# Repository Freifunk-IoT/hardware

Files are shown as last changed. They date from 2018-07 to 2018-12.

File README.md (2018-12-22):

# Freifunk-IoT-Hardware

| Hardware/Details | Typ  | Messungen/Sensor | Stückpreis ca. | Status | Bemerkungen |
| --- | ---- | --- | --- | --- | --- |
| [ESP-03 mit BME280](https://github.com/Freifunk-IoT/hardware/blob/master/esp8266/enviroment/esp03_bme280/ESP03_BME280.md) | PCB  | BME280 (Temperatur, Luftfeuchtigkeit, Luftdruck) | ? | funktioniert (Rev. 2) | kann Deep Sleep, inkl. Sicherung |
| ESP-03 mit BME280/DHT22 (Hybrid) | PCB  | BME280 (Temperatur, Luftfeuchtigkeit, Luftdruck) oder DHT22 (Temperatur, Luftfeuchtigkeit) | ? | Idee | |
| ESP-01 mit DHT11 | Mod  | DHT22 (T) | ? | Idee | Modul gibt es fertig bei Aliexpress etc., vmtl. gut für den "schnellen Einstieg". |
| [ESP-01 mit DHT*/BME280 "Workshop Board"](https://github.com/Freifunk-IoT/hardware/blob/master/esp8266/enviroment/esp01_DHT22_USB/ESP01_DHT22.md) | PCB  | BME280 (Temperatur, Luftfeuchtigkeit, Luftdruck) oder DHT22 (Temperatur, Luftfeuchtigkeit) | ? | Hardware funktioniert und ist getestet, Software fehlt | Einsteigerplatine mit Linearregler (USB-Anschluss) + entsprechende Absicherung, wahlweise BME280 oder DHT*, kleinste Bauteile: 1206, alles andere THT |
| Outdoor-Full-Feature-Board | PCB  | BME280 | ? | Idee | inkl. BMS für LiIon, Spannungsreglern (Buck/Boost), Absicherungen, Deep Sleep, optimiert für lange Laufzeiten |
| Wemos D1 mini mit DHT* | PCB | DHT* (Temperatur + Feuchtigkeit) | ? | Idee | Für einfachen Einstieg (5V USB Eingang) |

Wenn du Freifunk-IoT auf anderer Hardware betreibst, neue Sensoren eingebunden hast, eine praktische Platine entworfen hast oder einfach nur dein Aufbau vorstellen willst, mach einfach einen eigenen Ordner für dein Projekt auf und stelle es vor!

*Bitte beachtet: Dieses Repository ist mehr für die technische Entwicklung und Vorstellung gedacht. Reine Tutorials sind auf der [website](https://github.com/Freifunk-IoT/website) besser aufgehoben.*

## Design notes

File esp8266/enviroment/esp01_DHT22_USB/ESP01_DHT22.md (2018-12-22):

# ESP-01 mit DHT22 und USB-Spannungsversorgung
(by [@morasp](https://github.com/morasp))
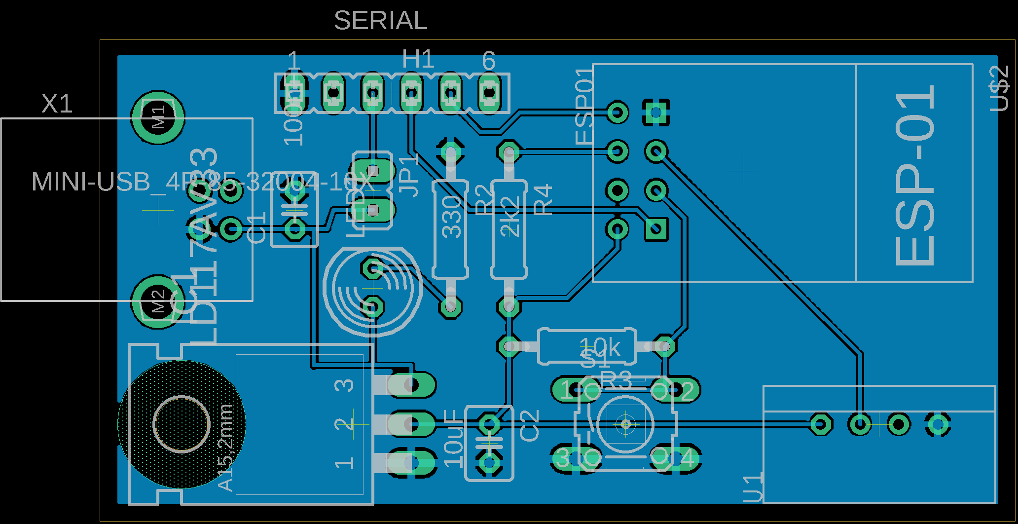
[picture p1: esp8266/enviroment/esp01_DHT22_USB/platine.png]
Vorläufige Platine


Diese Platine ist gedacht für Lötanfänger und Workshops. Deshalb sind alle Bauteile als THT ausgeführt. Außerdem erfolgt die Spannungsversorgung über USB.

### Features

- Temperatur- und Luftfeuchtigkeitsmessung mit DHT22
- direkter Anschluss eines Programmieradapters
- Spannungsversorgung über USB
- Keine SMD-Bauteile

### Bauteile
| Bezeichnung | Anzahl |
|---|---|
| Platine | 1|
| ESP-01 | 1|
| DHT22 | 1 |
| Widerstand 10k | 1 |
| Widerstand 2k2 | 1 |
| Widerstand 330 | 1 |
| Taster | 1 |
| USB-B Buchse  THT | 1 |
| Kondensator 100nF | 1 |
| Kondensator 10 uF | 1 |
| LF33ABV | 1 |
| Buchsenleiste 2,54 mm | 1 |
| Jumper | 1 |
| LED 5mm | 1 |

Genaue Teilebezeichungen, Preise und Links folgen.

### Changelog
Rev1:
Initial Layout

Rev2:
Fixed Programmer-Pinout to fit FTDI-Breakout

Rev3:
Changed voltage-regulator to fit pseudo-standart pinout

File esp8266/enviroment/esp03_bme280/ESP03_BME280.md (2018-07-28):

# ESP-03 mit BME280 

(by [@margau](https://github.com/margau))

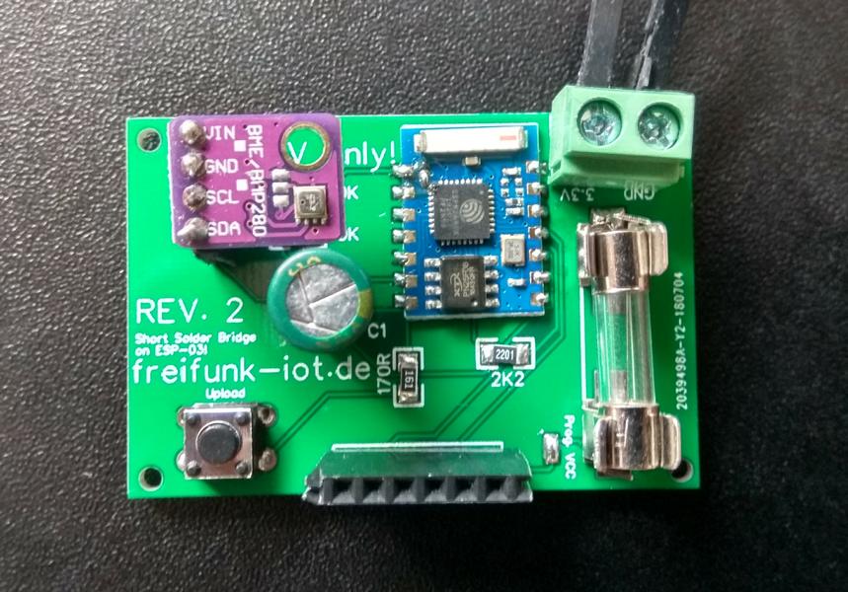
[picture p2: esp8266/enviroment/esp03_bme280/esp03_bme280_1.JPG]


Diese Platine bietet, unter Verwendung von SMD-Bauelementen, einen schnellen Aufbau eines Temperatursensors an. Nötig ist zum Betrieb nur eine externe 3,3V-Spannungsversorgung. Auf LED's etc. wurde verzichtet, um einen möglichst lange andauernden Akkubetrieb möglich zu machen. Der Aufbau dauert für geübte ca. 10-15 Minuten.

### Features

- Temperatur-, Luftfeuchtigkeits und Luftdruckmessung mit BME280
- Sicherung
- direkter Anschluss eines Programmieradapters

### Bauteile

| Bezeichnung | Quelle | Anzahl | Preis (07/2018) |
| --- | --- | --- | --- |
| Platinen | JLCPCB | 1 (10er Set) | 10 Stück: ~10 €  inkl. Versand |
| ESP-03 | China (Ebay, Ali...) | 1 | ~ 2,20 € |
| BME280 4-pin-Breakout | Amazon, Ebay, Aliexpress | 1 | ~ 2,20€ - 10 €/Stück |
| Elektrolytkondensator (z.B. 330 µF 16V) | Jeder Elektronikhändler, Empf.: Sets | 1 | < 0,10 € |
| SMD-Widerstand 1206 10kΩ | Jeder Elektronikhändler, Empf.: Sets | 2 | ~ 1ct/Stück |
| SMD-Widerstand 1206 2,2kΩ | Jeder Elektronikhändler, Empf.: Sets | 1 | ~ 1ct/Stück |
| SMD-Widerstand 1206  170Ω | Jeder Elektronikhändler, Empf.: Sets | 1 | ~ 1ct/Stück |
| Feinsicherung 1A 6*20mm | Jeder Elektronikhändler, Empf.: Sets | 1 | |
| Sicherungshalter | Conrad:  533920 - 62, Ali, einige Elektronikhändler | 2 | ~ 14ct/Stück Conrad, ~1,20 € für 100 Stück (Aliexpress) |
| Buchsenleiste 2,54 mm | Diverse Elektronikhändler, am besten als Set | 1 * 4 pin, 1 * 6 pin | Aliexpress: 1,66 € für 10 * 40 pins |
| 5,08 mm Schraubklemme | Ebay, Aliexpress ... | 1 | ~ 1,20 € für 20 Stück |
| Miniaturtaster | Ebay, Aliexpress; sinnvoll im Set | 1 | < 10 ct |
| FTDI232(o.ä.) USB-Seriell Programmieradapter, **3.3V!**, auf Pinbelegung achten! | Ebay, Aliexpress, ... | 1 | ~1,50 € |

Weiterhin wird für den Betrieb eine 3.3V-Spannungsversorgung benötigt, auch hier gibt es fertige Module. **Ein Betrieb mit 5V zerstört die Schaltung!**

### PCB
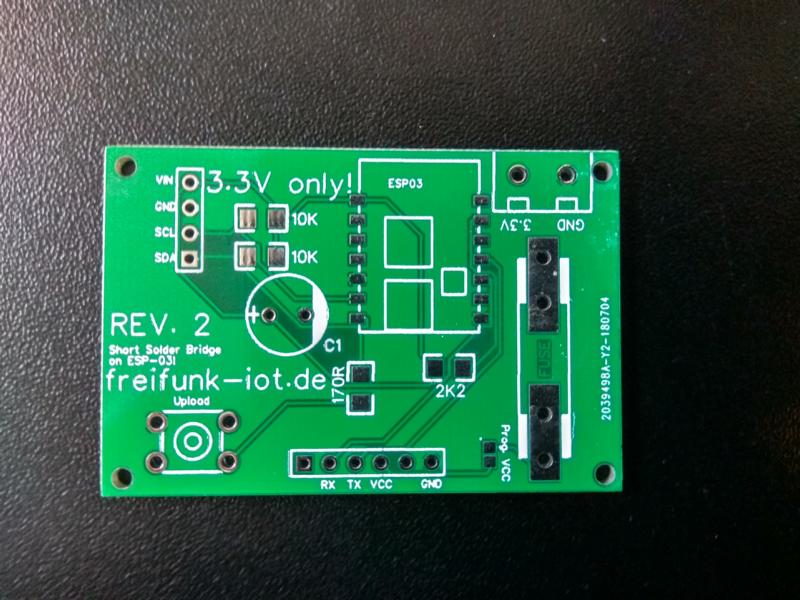
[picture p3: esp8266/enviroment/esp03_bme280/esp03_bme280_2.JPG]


Die Produktionsdaten im Gerber-Format befinden sich im Ordner "Gerber". Das Design ist im Onlineeditor von EasyEDA entstanden, und kann dort auch weiterbearbeitet werden: [Zum Projekt bei EasyEDA](https://easyeda.com/margau/FreifunkIoT-BME280-ESP03)

Die im Bild dargestellte Platine wurde bei JLCPCB bestellt, bei Kosten von ca. 9$ für 10 Stück inkl. Versand und einer Lieferzeit von ca. 10-20 Tagen.

### Aufbau
Es empfiehlt sich beim Aufbau zunächst mit den SMD-Komponenten zu beginnen, und sich dann zu den größeren Bauteilen vorzuarbeiten.
Wenn beim Programmiervorgang eine Stromversorgung über den Programmieradapter gewünscht ist, muss die Lötbrücke Prog. VCC geschlossen werden.

Bei Verwendung des Deep Sleep muss weiterhin eine Lötbrücke auf der Platine des ESP-03 geschlossen werden, dies erfordert etwas Geschick und Vorsicht.

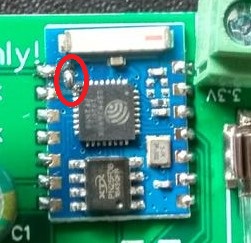
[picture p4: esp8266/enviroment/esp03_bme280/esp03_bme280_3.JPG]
Lötbrücke


Man kann das BME280-Breakout-Board direkt verlöten, oder (besonders im Falle eines defektes) austauschbar über eine Buchsenleiste montieren. Hierbei einfach darauf achten, dass die Beschriftung am BME280-Breakout-Board mit der auf der Platine übereinstimmt.

Die externe Stromversorgung des Boards **muss** mit 3.3V erfolgen, andernfalls werden Bauteile beschädigt.

### Programmierung
Die Programmierung erfolgt mit einem USB-Seriell-Adapter aus der Arduino-IDE. 
Hierzu ist folgender Sketch geeignet: (https://github.com/Freifunk-IoT/esp8266-examples/blob/master/bme280/esp01/esp01-bme280-sketch/esp01-bme280-sketch.ino)

Folgende Änderungen müssen noch vorgenommen werden:
- Die richtige Sensor-ID muss eingetragen werden
- ggf. den Kommentar in Zeile 143 entfernen und Zeile 145 auskommentieren, um den Deep Sleep zu nutzen

In der Arduino-IDE muss die ESP8266-Umgebung installiert sein, der richtige COM-Port ausgewählt werden und das Board "Generic ESP 8266 Module" ausgewählt sein. 

Nach korrekter Verbindung (Pin's prüfen!) und Einstellung der Spannung von **3.3 V** am USB-Seriell Adapter kann man den Upload-Knopf am Board gedrückt halten, die Verbindung herstellen und in der IDE den Upload anstoßen. 

Sieht man an den LEDs des Adapters einzelnes Aufblitzen, kann der Upload-Taster losgelassen werden; der Upload sollte nun erfolgen. Falls nicht, sind noch einmal alle Verbindungen etc. zu prüfen.

*Die Beschriftung am Programmieranschluss ist 1:1, d.h., RX wird mit RX am Adapter und TX mit TX am Adapter verbunden. Die Belegung ist die der üblichen FTDI232-Adapter - falls eine andere Reihenfolge der Pins vorliegt, einfach mit Jumper-Kabeln richtig verbinden.*

Nach dem Upload lässt sich über die Serielle Schnittstelle das Verhalten nachvollziehen, der Sensor sollte bei vorhandenem Freifunk-Netz direkt im Freifunk-IoT-Backend auftauchen.

### Changelog
Rev 1:  
Initial Layout

Rev 2:  
Added missing pull-up resistors, added missing GPIO15-GND connection.

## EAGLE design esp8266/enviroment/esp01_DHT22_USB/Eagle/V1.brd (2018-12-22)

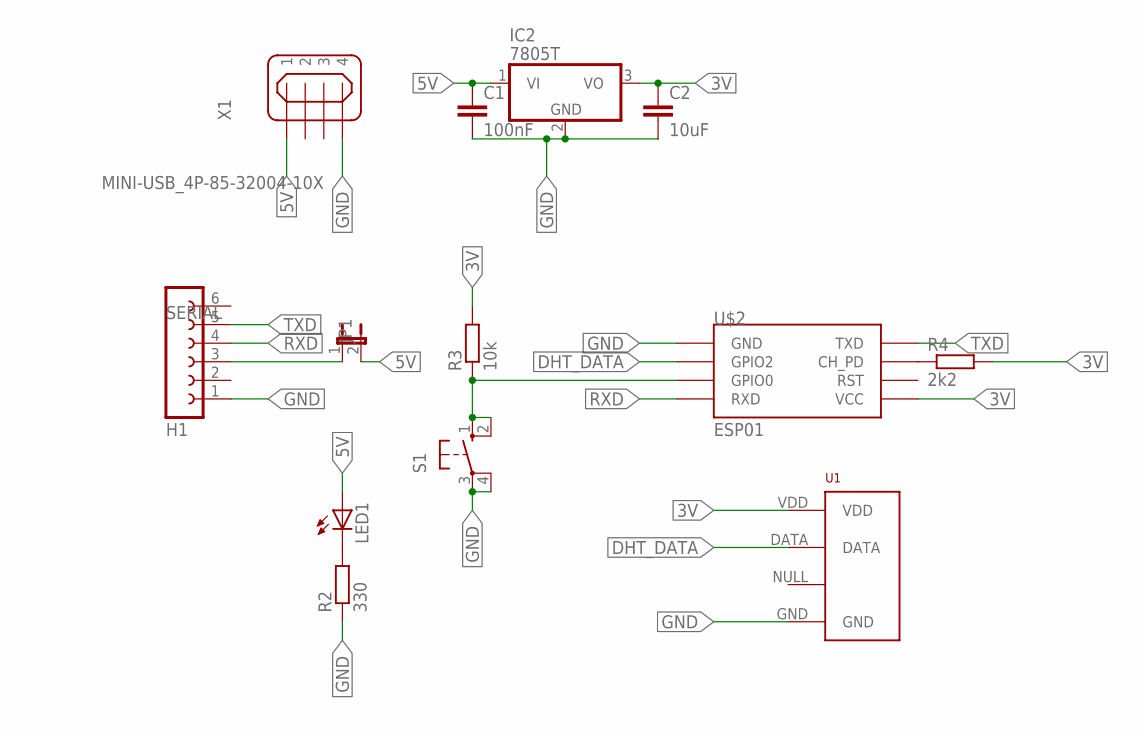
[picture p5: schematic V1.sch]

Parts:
C1: 100nF; C025-030X050
C2: 10uF; C025-030X050
IC2: 7805T; TO220H
JP1: JP1E; JP1
LED1: LED5MM
R2: 330; 0207/10
R3: 10k; 0207/10
R4: 2k2; 0207/10
S1: 10-XX; B3F-10XX
SERIAL: H1; FE06
U1: RHT03_DHT-22_AM2302; RHT03_DHT-22
U$2: ESP01
X1: MINI-USB_4P-85-32004-10X; 85-32004-10X

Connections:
3V: C2.1, IC2.3 (VO), R3.2, R4.2, U1.VDD, U$2.VCC
5V: C1.1, IC2.1 (VI), JP1.2, LED1.A, X1.1
DHT_DATA: U1.DATA, U$2.GPIO2
GND: C1.2, C2.2, IC2.2 (GND), R2.1, S1.3, S1.4 (P1), SERIAL.1, U1.GND, U$2.GND, X1.4
unnamed: JP1.1, SERIAL.3
unnamed: LED1.K (C), R2.2
unnamed: R3.1, S1.1 (S), S1.2 (S1), U$2.GPIO0
unnamed: R4.1, U$2.CH_PD
RXD: SERIAL.4, U$2.RX (RXD)
TXD: SERIAL.5, U$2.TX (TXD)

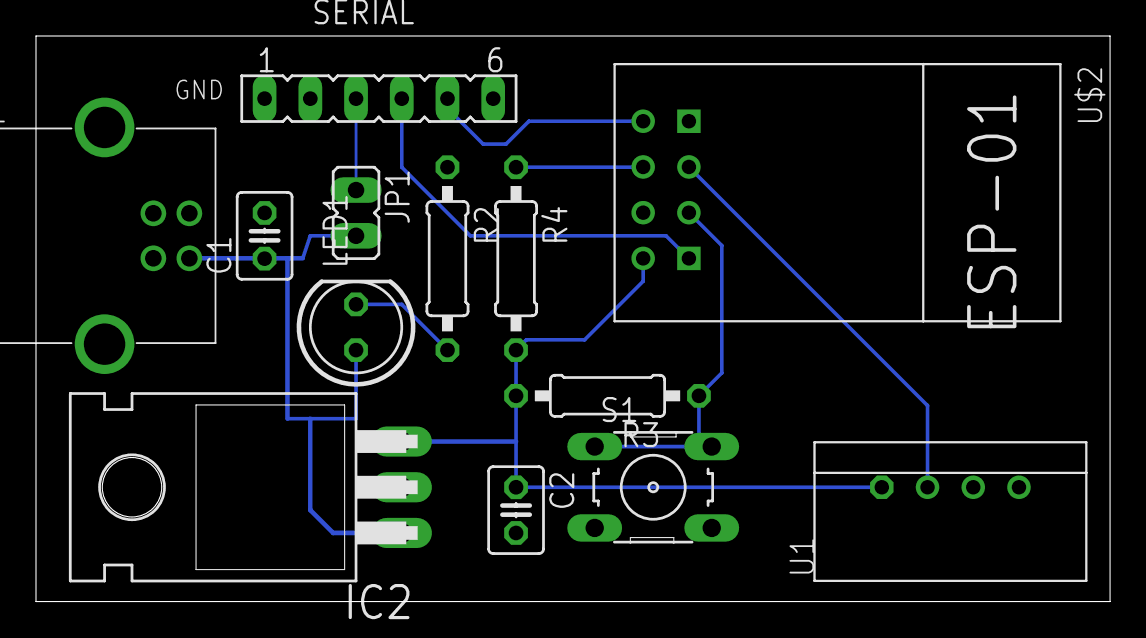
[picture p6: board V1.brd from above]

Board: 2 copper layers, 59.7 x 31.4 mm, 13 parts (0 on the bottom side), 10 nets.

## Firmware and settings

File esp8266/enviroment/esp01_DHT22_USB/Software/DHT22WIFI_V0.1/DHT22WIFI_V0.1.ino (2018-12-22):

#include <DHT.h>
#include <ESP8266WiFi.h>
#include <WiFiClient.h>
#include <ESP8266HTTPClient.h>
#include <ESP8266mDNS.h>


#define SENSORID "MSP_01"

#define DHTPIN 2    // what digital pin the DHT22 is conected to
#define DHTTYPE DHT22  // there are multiple kinds of DHT sensors

DHT dht(DHTPIN, DHTTYPE);

const char *ssid = "*****";
const char *password = "*****";

const char *url = "http://demo.freifunk-iot.de/input?";

void sendTemp(){
  Serial.println("Send Temp");
  HTTPClient http;
  float h = dht.readHumidity();
    // Read temperature as Celsius (the default)
  float t = dht.readTemperature();
  if (isnan(h) || isnan(t)) {
      Serial.println("Failed to read from DHT sensor!");
        delay(100);
      return;
    }
  String URL = url+String(SENSORID)+".temp="+String(t);
  http.begin(URL);
  int httpCode = http.GET();
  if(httpCode==200){
    Serial.println(http.getString());
  }else{
    Serial.println("ERROR");
  }
  http.end();
}
void sendHum(){
Serial.println("Send Temp");
  HTTPClient http;
  float h = dht.readHumidity();
    // Read temperature as Celsius (the default)
  float t = dht.readTemperature();
  if (isnan(h) || isnan(t)) {
      Serial.println("Failed to read from DHT sensor!");
        delay(100);
      return;
    }
   String URL = url+String(SENSORID)+".hum="+String(h);
  http.begin(URL);
  int httpCode = http.GET();
  if(httpCode==200){
    Serial.println(http.getString());
  }else{
    Serial.println("ERROR");
  }
  http.end();
}


void setup()
{
    Serial.begin(115200);
    Serial.setTimeout(2000);
    dht.begin();
    WiFi.mode(WIFI_STA);
    WiFi.begin(ssid, password);
    Serial.println("WIFI-Thermometer");

  
 
    Serial.println("");

    // Wait for connection
    while (WiFi.status() != WL_CONNECTED) {
      delay(500);
      Serial.print(".");
    }

  Serial.println("");
  Serial.print("Connected to ");
  Serial.println(ssid);
  Serial.print("IP address: ");
  Serial.println(WiFi.localIP());

  if (MDNS.begin("esp8266")) {
    Serial.println("MDNS responder started");
  } 
    float h = dht.readHumidity();
    // Read temperature as Celsius (the default)
    float t = dht.readTemperature();
    // Read temperature as Fahrenheit (isFahrenheit = true)
    float f = dht.readTemperature(true);

    // Check if any reads failed and exit early (to try again).
    if (isnan(h) || isnan(t) || isnan(f)) {
      Serial.println("Failed to read from DHT sensor!");
      delay(500);
      return;
    }

    // Compute heat index in Fahrenheit (the default)
    float hif = dht.computeHeatIndex(f, h);
    // Compute heat index in Celsius (isFahreheit = false)
    float hic = dht.computeHeatIndex(t, h, false);

    Serial.print("Humidity: ");
    Serial.print(h);
    Serial.print(" %\t");
    Serial.print("Temperature: ");
    Serial.print(t);
    Serial.print(" *C ");
    Serial.print(f);
    Serial.print(" *F\t");
    Serial.print("Heat index: ");
    Serial.print(hic);
    Serial.print(" *C ");
    Serial.print(hif);
    Serial.println(" *F");

}

void loop()
{
    sendTemp();
    delay(2100);
    sendHum();
    delay(10000);
}

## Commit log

2018-07-28 Added Gerber
    [Gerber_BoardOutline.GKO, Gerber_BottomLayer.GBL, Gerber_BottomSolderMaskLayer.GBS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]
2018-07-28 Added Workshop-Board
2018-10-29 First commit for Workshop-Board
    [V1.brd, V1.sch]
2018-10-29 Changed Programmer-Pinout
    [V1.brd, V1.sch]
2018-12-01 Changed Voltage-Regulator to fit pseudo-standart pinout
    [V1.GBL, V1.GBO, V1.GBP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]
2018-12-08 Update README.md
    Updated infos about the "Workshop-board"
2018-12-22 Added Software
    [V1.brd]
